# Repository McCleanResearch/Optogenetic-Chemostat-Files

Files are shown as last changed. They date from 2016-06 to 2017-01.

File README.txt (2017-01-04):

December 01, 2016
Cameron Stewart, cstewart7@wisc.edu
Research Technician at UW-Madison
Principal Investigator: Megan McClean, mmcclean@wisc.edu
Lab website: http://mccleanlab.bme.wisc.edu

-----------------------------------------------------------------------
RELATED ARTICLE:
Stewart, C., McClean, M. N. Design and Implementation of an Automated 
Illuminating, Culturing, and Sampling System for Microbial Optogenetic 
Applications. J. Vis. Exp. (), e54894, doi:10.3791/54894 (2016).

--------------------------------------------------------------------------------------
SUMMARY: This repository contains files for creating a continuous culturing apparatus
for the purpose of studying the effects of light exposure on cultured microbes
by microscopy. At a high level: The user will use "Micro-Manager" to control a
microscope, FIJI to analyze the images, an arduino microcontroller to control
peristaltic pumps and a heating pad, and the "Bioreactor_Controller" plugin of MicroManager
 to coordinate these activities.
---------------------------------------------------------------------------------------
-The "Bioreactor_Controller.jar" file is the heart of this kit. It should be
copied into the Fiji/mmplugins folder AND ALSO into the Fiji/plugins folder. This 
controls the microscope, performs the image analysis (or calls an optional Beanshell 
script to perform the image analysis), sends parameters to the microcontroller which 
regulates power to the peristaltic pumps and heating pad of the continuous culturing 
vessel, and it can call external scripts for supplementary analysis or feedback control.

	--To use this to control a bioreactor and microscope, configure micromanager as a Fiji
	plugin (see the extensive manual for verbose instructions). Note that the image analysis 
	can easily be modified from the default settings by using an image anlysis script. I recommend
	using the "Image_Analysis_Script.bsh" as a starting point for custom analysis. Open it by 
	opening Fiji>Macros>Record. Then select "Beanshell" from the Record menu. Then click a button 
	that is recorded. Then click Create. Then go to File>Open to open this script. The portions
	that are most useful to edit are: preProcess() at line 49 and makeBinary() at line 67.
		Youtube demonstration: https://www.youtube.com/watch?v=FP84-2O_o3E

	--To use "Bioreactor_Controller.jar" to retrospectively analyze images, call the plugin from
	Fiji>Plugins>McCleanLab Analyze Bioreactor Images. Note that the images were collected
	from an experiment. To get images in a virtual stack (for when there are too many for the RAM), 
	I recommend copying them into a folder, and then opening them as a virtual stack via
	Fiji>File>Import>Image Sequence.
		YouTube demonstration: https://www.youtube.com/watch?v=LyaSNZRGDJk

	--To use the "Bioreactor_Controller.jar" to plot image analysis results, call the plugin from
	Fiji>Plugins>McCleanLab Plot Bioreactor Results. Note that the beginning of the video displays the CSV values that were
	generated by the aforementioned image analysis plugin and later plotted. Also note that this plugin requires
	JHeatChart.jar to be in the Fiji/Jars folder.
		YouTube demonstration: https://youtu.be/8iOyvxAbDik

-The "extensive_lab_manual....docx" document in this repository is intended to describe
all of the steps needed to build this, and useful figures along the way. It is a verbose
version of the paper:
Stewart, C., McClean, M. N. Design and Implementation of an Automated 
Illuminating, Culturing, and Sampling System for Microbial Optogenetic 
Applications. J. Vis. Exp. (), e54894, doi:10.3791/54894 (2016).
Improvements and troubleshooting tips, especially with regard to
the software, will be listed here.

-The ".fzz" file contains the design for a printed circuit board that can be stacked 
on an Arduino microcontroller and be used to regulate power to external devices, read
inputs from an external thermometer, and control an LED matrix. To build the apparatus
described in the manual, the reader will need to order a circuit board with this
design. It can be opened with the Fritzing software which is free and open-source.
An additional use for this, besides ordering the board, is that the user can inspect
the connections in the PCB and/or modify it for another purpose.

-The "microcontroller_code" folder contains code that should be uploaded to the
microcontroller and its own "readme"

-The "bioreactorTimecourse.csv" file contains a 3 columns of values. The first
is a column of time values. The second is a column of the number of LEDs of the 
LED matrix that should be on (0-64), and the third is the pulse-width-modulated
intensity of those LEDs (0-255). Together, they dictate how the microcontroller
control the LED matrix over time. It is not necessary, but it may be useful to
use this file instead of manually entering these values into the "bioreactorController"
plugin.

-The "supplementary_scripts" folder contains Beanshell (a java-like language) scripts
that can be used in place of the plugin. The downside of using these scripts is that they
may not be synchronized with the plugin code. The benefit of using them is that they can
be easily customized in the beanshell script editor.

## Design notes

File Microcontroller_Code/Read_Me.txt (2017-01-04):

Add the subfolders in the "add_these_to_library" folder to the "libraries" subfolder
of the "Arduino" folder. On windows, the default location for this is "Program Files (x86)"

When using the bioreactor plugin, ensure that the "Microcontroller_Code_Use_With_Bioreactor_Control_Plugin.ino"
software is the most recently uploaded software to the Arduino. The other .ino file is only useful for 
troubleshooting. It turns the pumps on and off, and it iterates through various LED matrix settings.

WARNING! If the hard-coded version is used with the plugin, the microcontroller will not follow the instructions
from the plugin, and it will be useless.

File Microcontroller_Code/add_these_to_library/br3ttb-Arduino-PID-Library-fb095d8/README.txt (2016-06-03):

2/3/2016- This code was not written by Cameron Stewart (username stewarc8), but it is useful as a part of the arduino chemostat 
controller.
***************************************************************
* Arduino PID Library - Version 1.1.1
* by Brett Beauregard <br3ttb@gmail.com> brettbeauregard.com
*
* This Library is licensed under a GPLv3 License
***************************************************************

 - For an ultra-detailed explanation of why the code is the way it is, please visit: 
   http://brettbeauregard.com/blog/2011/04/improving-the-beginners-pid-introduction/

 - For function documentation see:  http://playground.arduino.cc/Code/PIDLibrary

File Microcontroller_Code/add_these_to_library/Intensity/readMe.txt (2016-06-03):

The Intensity files are used to control the intensity of light emitted by an 8x8 LED matrix, driven by a MAX7219 driver, and controlled
by an Arduino. It controls the number of lights ON in the range of 0 to 64, and it controls their individual intensities via pulse-width-
modulation (PWM). For the lights in the range of 1-64, as much as possible, lights are turned on symmetrically from the center outward.

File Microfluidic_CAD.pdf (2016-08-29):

Length = 2 cm

Width = 1 mm
Diameter | Height = 75 μm
=1.5 mm

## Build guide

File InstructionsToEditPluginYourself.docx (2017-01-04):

I’ve only ever used Eclipse, and so these instructions are for eclipse. The are largely based on these instructions : Configure Eclipse to edit a plugin at https://www.micro-manager.org/wiki/Writing_plugins_for_Micro-Manager

These steps assume that you have already followed these instructions:

  1.1.) Download and install FIJI³¹.
  1.2.) Download and configure Micro-Manager²⁹,³⁰ as a FIJI plugin³¹.
    1.2.1) From the directory into which micromanager was downloaded, copy all of the “libmmgr_dal” files and paste them into the Fiji.app directory. Similarly, copy the “mmplugins” directory and the “mmautofocus” directory from the micromanager directory to the Fiji.app directory.
    1.2.2) Copy the “plugins/Micro-Manager” directory from the micromanager main directory to the “plugins” directory in the Fiji.app directory.

Copy the BioreactorController folder to your Eclipse workspace, then follow the next 5 steps to get eclipse to actually recognize it (taken from this link: http://stackoverflow.com/questions/3924229/adding-existing-project-folders-to-the-project-explorer-in-eclipse”

1. From the main menu bar, select File > Import. The Import wizard opens.

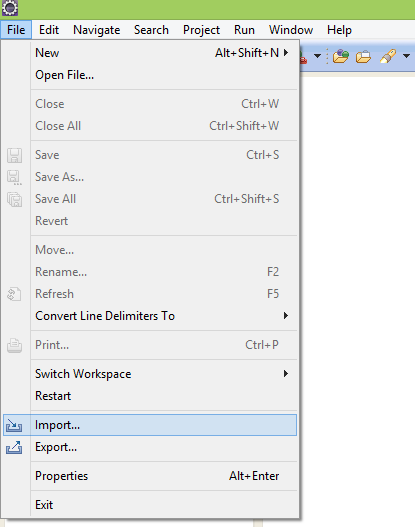
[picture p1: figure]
enter image description here

2. Collapse or click + in General > Existing Project into Workspace and click Next.

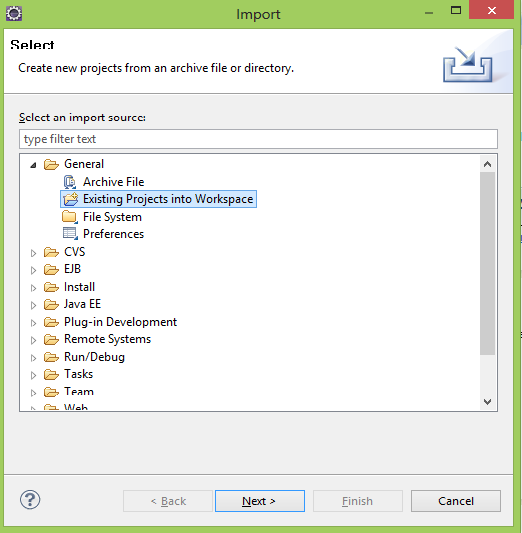
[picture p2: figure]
enter image description here

3. Choose either Select root directory or Select archive file and click the associated Browse to locate the directory or file containing the projects.

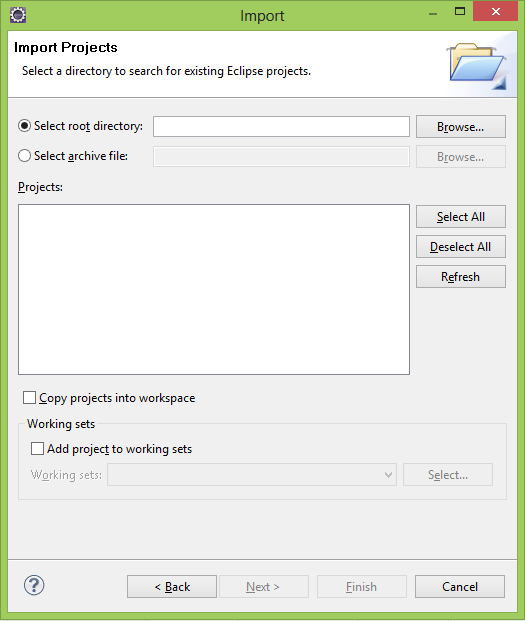
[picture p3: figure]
enter image description here

4. Under Projects select the project or projects which you would like to import.

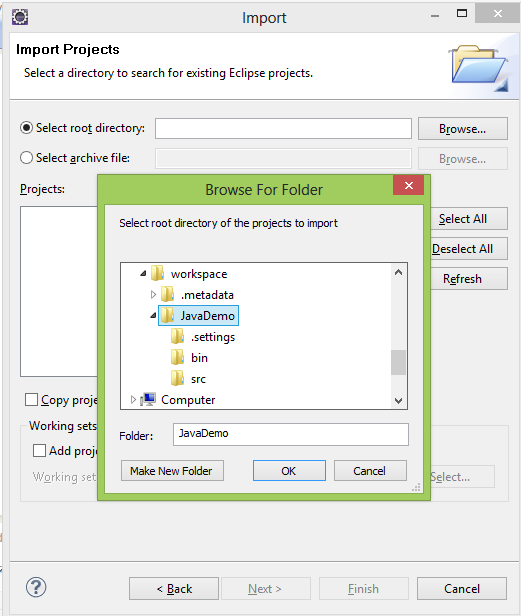
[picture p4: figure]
enter image description here
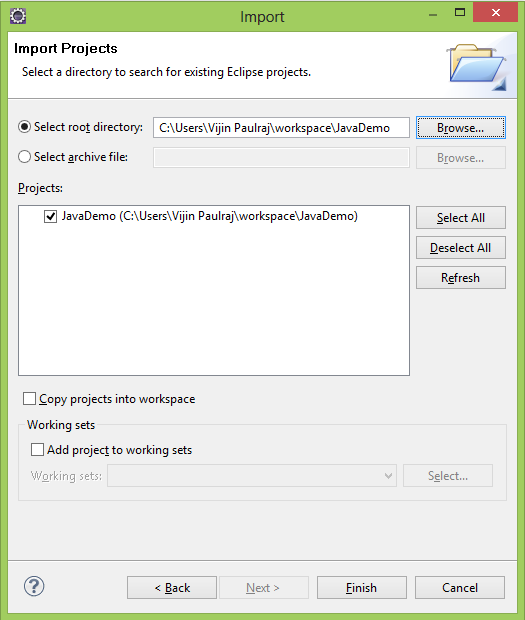
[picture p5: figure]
enter image description here

5. Click Finish to start the import.

Ok, now you should have the project in the folder. Open the “src” folder, and navigate to the “.java” files. You will likely see a bunch of import error like this:

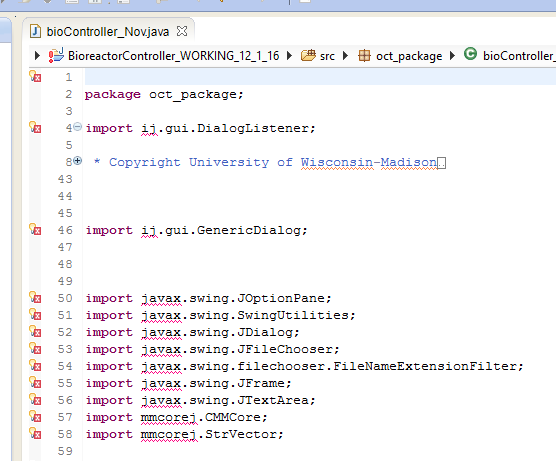
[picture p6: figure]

This code references external JARs from micromanager and imageJ, and so the build path needs to be configured.

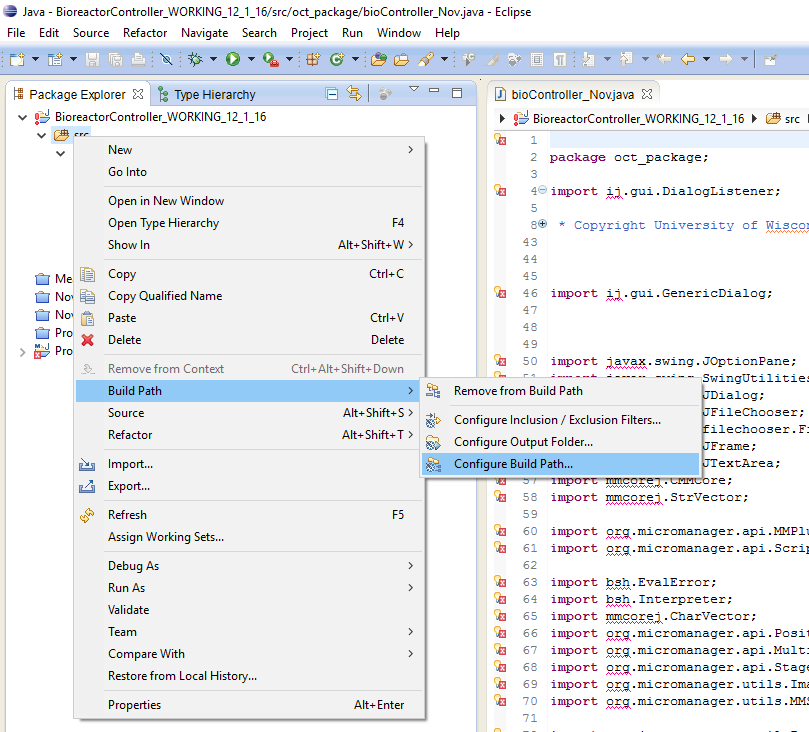
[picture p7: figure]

And then add External JARs…

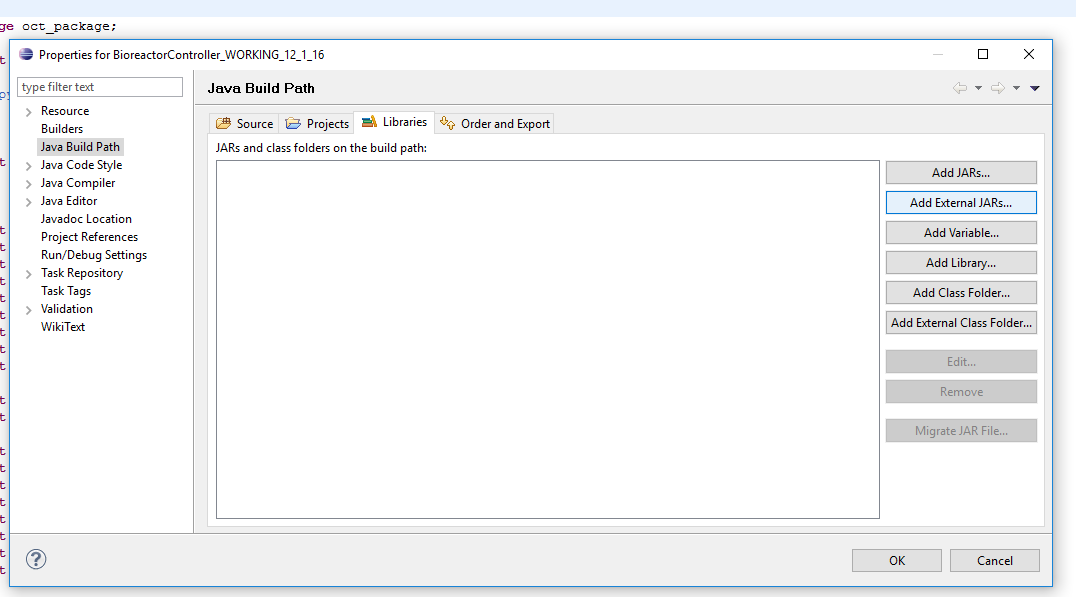
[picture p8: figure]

This part is a bit tedious. Add every JAR in the FIJI download folder. To do this quickly, click one and then hold shift + ↓ to select many, or use Ctrl+a in Windows to select all.

- Everything in the “jars” folder of the FIJI download.
- Everything in the “plugins\Micro-Manager” folder of the FIJI download.
- Everything in the “plugins” folder. I just did Ctrl+a in Windows to select all jars and subfolders. Note that this instruction might be redundant with the one above. I specify the one above to ensure that it is definitely included.

Next, ensure that you use the same JRE as FIJI by :

Add FIJI’s JRE to Eclipse

1. Window -> Preferences; under Java, select Installed JREs and click Add...
  1. Use Standard VM
  2. Set the JRE Home to C:\Users\Cameron\Downloads\fiji-win64\Fiji.app\java\win64\jdk1.8.0_66\jre (or similar).
  3. Eclipse should fill in the rest.
  4. Consider making thismanager JRE the default, or when you create projects make sure to select this as the JRE
  5. Click Finish
2. Check the checkbox next to the newly-added JRE.

Then, ensure that the project uses that same JRE:

Project > Properties > Java Build Path > Libraries

Add Library... > JRE System Library

Click “Alternate JRE:”, the “Installed JREs”, then select the newly added FIJI JRE, the click “Ok” and then “Finish”

Ok, now there should not be errors. If you have errors, a Google search of the error will usually return a StackOverflow page that describes exactly how to fix it. Good luck!

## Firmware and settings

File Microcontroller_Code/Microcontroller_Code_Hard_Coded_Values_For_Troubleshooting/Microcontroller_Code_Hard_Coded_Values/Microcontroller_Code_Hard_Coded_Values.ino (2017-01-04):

#include <Intensity.h>
#include <OneWire.h>
#include <DallasTemperature.h>
#include <PID_v1.h>
//USE THIS ONLY FOR TROUBLESHOOTING
//To check the temperature go to tools> Serial monitor and senbd "immeC,1,0.08" where the first number is the media pump ratio, the second is the sample pump ratio

//**************************DEFINE PINS***************************************************************************
// LED ARRAY SETUP*************                                                                                  
//DIN, pin 1 on MAX7219, is connected to pin 2 on the arduino
# define DATA_IN 2

//LOAD(CS), pin 12 on MAX7219, is connected to pin 3 on arduino
# define LOAD 12//formerly 3

//CLK, pin 13 on MAX7219, is connected to pin 4 on arduino
# define CLOCK 13//formerly 4

//THERMOMETER SETUP***************
// Data wire of thermometer high temp DS18B20 is plugged into port 8 on the Arduino
#define ONE_WIRE_BUS 8

//PID CONTROLLED HEATING PAD
#define PIN_HEAT 3

# define MEDIA_PUMP 4  //Pin controlling media pump
# define SAMPLING_PUMP 5  //Pin controlling sampling pump

//Size of array to store timecourse message
# define ROWS 150
# define COLUMNS 2

# define MEDIA_PUMP_RATIO 0.5
# define SAMPLE_PUMP_RATIO 0.5

#define COMMAND_TERMINATOR "#"


//***********************DEFINE GLOBAL VARIABLES***************************************************************************
//LED ARRAY INITIAL VARIABLES- default off
int LEDs=0;//Number of LEDs to turn on
int pwm=0;//Brightness of LED array
Intensity blueArray(DATA_IN, LOAD, CLOCK);

//THERMOMETER INITIAL VARIABLES
// Setup a oneWire instance to communicate with any OneWire devices (not just Maxim/Dallas temperature ICs)
OneWire oneWire(ONE_WIRE_BUS);
// Pass our oneWire reference to Dallas Temperature. 
DallasTemperature sensors(&oneWire);

//PID CONTROLLED HEATING PAD INITIAL VARIABLE
//Define Variables we'll be connecting to
double Setpoint=30;//Default to 30C target. I intentionally did not make a way to change this because I wanted to keep it at 30C.
      //However, a temperature experiment could be done by feeding a set of temperatures to the timecourse array
double Output=64;//64
double Input=3.14;//A non-zero initial value is useful for troubleshooting because
                  //an improper connection often returns the value 0.00 (if not connected to anything)
//Specify initial tuning parameters
double Kp=.02, Ki=.05, Kd=.01;

PID myPID(&Input, &Output, &Setpoint, Kp, Ki, Kd, DIRECT);

//PUMP INTIAL VARIABLES
int mediapumpPWM=255; //starting ON is useful because they can be manually turned off
int samplingpumpPWM=255;
float mediaRatioOn=MEDIA_PUMP_RATIO;
float sampleRatioOn=SAMPLE_PUMP_RATIO;

//VARIABLES TO STORE TIMECOURSE MESSAGE
long updateTime[ROWS]; //This will store update times in seconds. Not in milliseconds
char updateVals[ROWS][COLUMNS]; //A char array is used to conserve memory
int timecourseRow=-1; //This will be used to track the row in the timecourse array
                      //-1 indicates that the timecourse array is not ready.
unsigned long startTime=0;
unsigned long thirtiesPast=0; //used to pulse media pump within a 30 seconds period

unsigned long counter=0;

//***********BEGINING OF METHODS AND FUNCTIONS**************************************************************************

void setup() {
  Serial.setTimeout(50);
  pinMode(PIN_HEAT,   OUTPUT);
  Serial.begin(9600);
  sensors.begin();
  sensors.requestTemperatures();
  Input=sensors.getTempCByIndex(0);
  myPID.SetMode(AUTOMATIC);
}

void loop() {
  counter++;
  char nextChar;
  Input=0;
  sensors.requestTemperatures();
  Input=sensors.getTempCByIndex(0);
  
    
  while (Serial.available() > 0) {
    //Read in "i,the ratio of time the media pump should be ON (pwm=255 vs pwm=0), PWM power to sampling pump pump,e"
    // 'i' initiates a message. 'e' ends the message
    nextChar=Serial.read();
    //"timeC" is the codeword indicating that a timecourse command will follow
    if (nextChar=='t'&&Serial.read()=='i'&&Serial.read()=='m'&&Serial.read()=='e'&&Serial.read()=='C'){//arbitrarily chosen charecter to indicate timecourse commands
      readTimecourseCommands(); //fills in timecourse array
      //"immeC" is the codeword indicating that an immediate command (for the pumps and lights and pinch valve) will follow 
    }else if(nextChar == 'i'&&Serial.read()=='m'&&Serial.read()=='m'&&Serial.read()=='e'&&Serial.read()=='C') { //arbitrarily chosen charecter to indicate immediate commands
      //This reduces the chance that  noise is read as signal
      readImmediateCommands();//updates mediaRatioOn, samplingpumpPWM
      sendTimeAndTemp();
    }
    //don't know what to do with this character in the Serial  buffer, must ignore it
  }
  
    while(timecourseRow>-1&&(millis()-startTime)>(updateTime[timecourseRow]*1000)){ // multiply timecourserow by 1000 to make into milliseconds
      // timecourse==-1 would indicate that the timecourse array should not be read. The second part
      //should should act as an IF statement under most conditions. But, if it ends up multiple rows behind, This lets it skip ahead to the proper row
      LEDs=(int)updateVals[timecourseRow][0];// The array holds chars (to be more compact) but other code expected an (int). To optimize this code,
      // the other code could be changed to expect a (char) 
      pwm=(int)updateVals[timecourseRow][1];
      //Setpoint=timecourse[timecourseRow][2];
      //If COLUMNS is set to 3, then timecourse could include a Setpoint (temperature) timecourse too
      //This was not done for now to conserve dynamic memory.
      timecourseRow++;
      if(timecourseRow>=ROWS)
        timecourseRow=-1; //indicate that there is nothing to do until the next message. It will stay on the last setting
  }
  myPID.Compute();
  analogWrite(PIN_HEAT, Output);

  blueArray.numLEDs(counter%65);//LEDs
  blueArray.PWM(counter%16);//pwm

  //The media pump is OFF for 25 seconds and ON for 5 seconds of every 30 seconds
  if((millis()-(thirtiesPast*30000))<((1-mediaRatioOn)*30000)){
    mediapumpPWM=0;
  }
  else if((millis()-(thirtiesPast*30000))<30000){
    mediapumpPWM=255;
  }
  else if((millis()-(thirtiesPast*30000))>=30000){
    thirtiesPast++;
    mediapumpPWM=0;
  }

    //The media pump is OFF for 25 seconds and ON for 5 seconds of every 30 seconds
  if((millis()-(thirtiesPast*30000))<((1-sampleRatioOn)*30000)){
    samplingpumpPWM=0;
  }
  else if((millis()-(thirtiesPast*30000))<30000){
    samplingpumpPWM=255;
  }
  else if((millis()-(thirtiesPast*30000))>=30000){
    thirtiesPast++;
    samplingpumpPWM=0;
  }
  analogWrite(MEDIA_PUMP,mediapumpPWM);
  analogWrite(SAMPLING_PUMP,samplingpumpPWM);
}

void readImmediateCommands(){
    mediaRatioOn=Serial.parseFloat();
    mediaRatioOn=MEDIA_PUMP_RATIO;//constrain(mediaRatioOn,0,1);
    sampleRatioOn=Serial.parseFloat();
    sampleRatioOn=SAMPLE_PUMP_RATIO;//constrain(sampleRatioOn,0,1);
}
void readTimecourseCommands(){
  int row=Serial.parseInt();
  if(row==0){//This signals the beginning of a new timecourse
    timecourseRow=0;
    startTime=millis();
    //signalProblem(1);
  }
  updateTime[row]=Serial.parseInt();//recieve time. ParseInt actually returns (long)
  //for below: conversion from long to char may cause compiler warnings because it is lossy. But this code implicitly requires that
  //the next two recieved values are less than 255, so we're fine.
  updateVals[row][0]=(char)Serial.parseInt();//receive number of LEDs. Convert to char (0-255 is a large enough range. Therefore, save as char)
  updateVals[row][1]=(char)Serial.parseInt();//recieve pwm.  Convert to char (0-255 is a large enough range. Therefore, save as char)
  Serial.print("[");
  Serial.print(updateTime[row]);
  Serial.print(", ");
  Serial.print((int)updateVals[row][0]);
  Serial.print(", ");
  Serial.print((int)updateVals[row][1]);
  Serial.print("]");
  Serial.print(COMMAND_TERMINATOR);
}
void sendTimeAndTemp(){
      Serial.print("StartTime (milliseconds) ->,");
      Serial.print(millis()-startTime);
      Serial.print(",Temperature ->,");
      Serial.print(Input);
      Serial.print(",Heating Pad PWM ->,");
      Serial.print(Output);
      Serial.print(",number of LEDs ON ->,");
      Serial.print(LEDs);
      Serial.print(",LED PWM ->,");
      Serial.print(pwm);
      Serial.print(',');
      Serial.print(COMMAND_TERMINATOR); //return the current time and temp in CSV format
}

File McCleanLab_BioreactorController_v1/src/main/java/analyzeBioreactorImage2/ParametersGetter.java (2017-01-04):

package analyzeBioreactorImage2;

import ij.IJ;
import ij.gui.GenericDialog;
import ij.gui.Plot;
import ij.gui.PlotWindow;
import java.awt.Button;
import java.awt.Checkbox;
import java.awt.Font;
import java.awt.TextArea;
import java.awt.TextField;
import java.awt.event.ActionEvent;
import java.awt.event.ActionListener;
import java.awt.event.ItemEvent;
import java.awt.event.ItemListener;
import java.awt.event.TextEvent;
import java.awt.event.TextListener;
import java.io.BufferedReader;
import java.io.FileNotFoundException;
import java.io.FileReader;
import java.io.FileWriter;
import java.io.IOException;
import java.text.SimpleDateFormat;
import java.util.Arrays;
import java.util.Date;
import java.util.LinkedList;
import java.util.List;
import java.util.Vector;

import javax.swing.JDialog;
import javax.swing.JFileChooser;
import javax.swing.filechooser.FileNameExtensionFilter;

import util.opencsv.CSVReader;



public class ParametersGetter implements ItemListener,ActionListener,TextListener {
	private String port = "COM4";
	private final double interval = 30;
	private double mediaPumpRatio = 0.5;
	private double samplePumpRatio = 0.5;
	private int backgroundImages = 5;
	private double settlingDelay = 20;
	private String roiGroup;
	private String roiPreset;
	private String intensityGroup;
	private String intensityPreset;
	private String darkGroup;
	private String darkPreset;
	private boolean reloadTimecourse = false;
	private double minSetDelay = 3;
	private int iterations = 1000;;
	private String[] groupOptions;
	private String[] presetOptions;
	private String[] acqGroups;
	private String[] acqPresets;
	private String saveImgDir;
	private String saveMetaDir;
	private String imageAnalysisScript;
	private String feedbackScript;
	private Font boldFont = new Font("Serif", Font.BOLD, 36);
	private  List<String[]> LED_timecourse = new LinkedList<String[]>();
	private String bgOperationFind = "Difference";
	private String bgOperationAnalyze = "Subtract";
	private String[] bgOperations= { bgOperationFind, bgOperationAnalyze };
	private boolean loadSettingsFromCsv=false;
	private String pathToSettings="";
	private boolean loadTimecourseFromCsv=false;
	private String pathToTimecourse="";
	private boolean callExternalImageAnalysis=false;
	private String pathToExternalImageAnalysis="";
	private Checkbox loadSettingsBox;
	private Checkbox loadTimecourseBox;
	private Checkbox replaceImageAnalysisBox;
	private Checkbox callFeedbackScriptBox;
	private Checkbox sendTimecourseAndRatiosNow;
	private final String LINESEPARATOR="\r\n";
	private SimpleDateFormat sdf = new SimpleDateFormat("yyyy-MM-dd_HH-mm-ss-z");
	private String curTime;
	private static final String imageTypeName="Tiff";
	private static final String imageTypeSuffix=".tiff";
	private String title;
	private int numPositions;
	private GenericDialog genD;
	public static final int secondsColumn=0;
	public static final int LEDsColumn=1;
	public static final int pwmColumn=2;
	public static final int valsRow=1; //The headers row should be at 0. This is the first row with values that I care about
	public double[] paParams={1000,10000,0.5,1.0}; //String array with [minArea, maxArea,minCircularity,maxCircularity] for particle analyzer
	private double maxEccentricity=3;
	private Button escapeButton=new Button("Escape after current set?");
	private JDialog dialog=new JDialog();
	private boolean escape=false;
	private Plot hoursCourse;
	private static final int plotLineWidth=5;
	private bioController_Nov caller=null;
	

	
	

	public ParametersGetter(String title, int numPositions,String[] cfg_groups, String[] cfg_presets,bioController_Nov caller) {
		if (this.LED_timecourse.size() == 0) {
			this.LED_timecourse.add(new String[] { "10", "0", "0" });
			this.LED_timecourse.add(new String[] { "20", "0", "0" });
			this.LED_timecourse.add(new String[] { "30", "0", "0" });
			this.LED_timecourse.add(new String[] { "40", "0", "0" });
			this.LED_timecourse.add(new String[] { "50", "0", "0" });
			this.LED_timecourse.add(new String[] { "60", "32", "8" });
			this.LED_timecourse.add(new String[] { "120", "0", "0" });
			this.LED_timecourse.add(new String[] { "180", "64", "15" });
			this.LED_timecourse.add(new String[] { "240", "0", "0" });
			this.LED_timecourse.add(new String[] { "300", "0", "0" });
		}
		this.title=title;
		this.numPositions=numPositions;
		this.groupOptions=cfg_groups;
		this.presetOptions=cfg_presets;
		this.roiGroup=this.groupOptions[0];
		this.roiPreset=this.presetOptions[0];
		this.caller=caller;
	}
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

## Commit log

2016-06-03 new updates
    asfg
    [FritzingDesign_Order_This_From_Fritzing_Services_version_08.fzz, bioreactorParameters.csv, bioreactorTimecourse.csv]
2016-06-03 edits
    edits
    [PCB_Design_v08.fzz, bioreactorParameters.csv, bioreactorTimecourse.csv]
2016-06-03 representativedata
    representative data
    [Results1.csv, Results10.csv, Results100.csv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]
2016-08-01 plugin
    script was converted to plugin
    [bioreactorParameters.csv]
2016-08-29 august update cad
2017-01-04 major upgrade
    Improved the plugin to be able to retrospectively analyze images and
    plot the data as a heat map and percentile plots
    [PCB_Design.fzz, PCB_Design_v08.fzz, Results1.csv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]
